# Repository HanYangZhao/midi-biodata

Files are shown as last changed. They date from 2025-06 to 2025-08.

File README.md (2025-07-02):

# MIDI Biodata Sonification Device

This repository was built upon code from https://github.com/electricityforprogress/BiodataFeather

Here you find the hardware and enclosure design files for the MIDI Biodata Sonification Devices

- enclosures: contains FreeCAD design and STL files for the enclosure
- firmware: 
  - MIDI_Psychogalv_328p_v021: unmodified firmware from electricityforprogress/MIDIsprout
  - arduino-nano: firmware for MIDI Biodata Sonification Device by me. This firmware offers the following new features over original version
    - Instead of menus, we use a web page to configure the device. The webpage uses webserial to send a json config to the board.
    - Allow all 7 modes of the major scale to be selected. I'm also included the chromatic and Raga Bhairav scale.
    - Selectable root note
    - Chord drone with selectable bpm and frequency. The chord is a triad based on the scale chosen.
    - Refactored code into multipe files for easier understanding.
    - Remove menu codes to save space, some optimization to free up the stack.
  - esp32: Same as main but for ESP32, the arduino-LEDFader folder needs to be copied to .../Arduino/Libraries. This firmware offer the additional:
    - 12 presets can be configured, each preset contains its own scale and root note, and can be triggered via MIDI CC/PC/NOTE
    - BLE MIDI support
- kicad: hardware design as KiCAD project and Gerber files. The board is designed to be used add-on to any microcontroller but also has footprint for the esp32s3 supermini board.

The hardware design and firmware is based on the work of electricityforprogress and thus licensed under the MIT license.

The enclosure design is however licensed under CC0 (public domain), except for the logo which is under copyright of [DipthDesign](https://www.dipth.de). For private use, anyone is free to print the enclosure with logo and without permission.

## Installation 

### Arduino nano

Download https://github.com/jgillick/arduino-LEDFader/tree/master to .../Arduino/Libraries

### ESP32

* Copy ./firmware/esp32/arduino-LEDFader to .../Arduino/Libraries
* Install arduino tiny usb library
* Device mode only support S2/S3/P4 and additional Tools menu are needed
    USB Mode=USB-OTG (TinyUSB) for S3 and P4
    USB CDC On Boot=Enabled, USB Firmware MSC On Boot=Disabled, USB DFU On Boot=Disabled
* BLE MIDI only works on ESP32-S3

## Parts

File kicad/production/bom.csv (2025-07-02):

Designator | Footprint | Quantity | Value | LCSC Part #
_4, _3, _2, | Fiducial_1mm_Dia_2.54mm_Outer_CopperTop | 4 | Fiducial_1mm_Dia_2.54mm_Outer_CopperTop
C1, C2, C4, C6 | 0402 | 4 | 0.1uF | C1525
C3 | 0402 | 1 | 4.7nF | C1538
C5 | CP_Radial_D5.0mm_P2.50mm | 1 | 100uF
D1 | D_SOD-123 | 1 | 1N4148W | C81598
D2 | 0603 | 1 | LED_WHITE | C2290
D3 | 0805 | 1 | LED_BLUE | C34499
D4 | 0805 | 1 | LED_GREEN | C2297
D5 | 0805 | 1 | LED_YELLOW | C2296
D6, D7 | 0603 | 2 | LED_RED | C2286
D8, D9 | D_SOD-882 | 2 | D_TVS | C294611
J1, J8 | DIN-5-MIDI-JACK | 2 | DIN-5_180degree
J3 | PinHeader_1x13_P2.54mm_Vertical | 1 | Conn_01x14_Pin
J7 | PinHeader_1x02_P2.54mm_Vertical | 1 | Conn_01x02_Socket
R1, R10, R11, R2, R3, R4, R5, R8, R9 | 0402 | 9 | 220R | C25091
R12 | 0805 | 1 | 470 | C17710
R6 | 0402 | 1 | 100K | C25741
R7 | 0805 | 1 | 3.9K | C17614
U1 | SOT-23-5 | 1 | SN74LVC1G07DBVR | C7829
U2 | tlp2362 | 1 | TLP2362TPR_E | C37658
U3 | DIP-8_W7.62mm | 1 | LMC555xM
U4 | MODULE_ESP32-C3_SUPERMINI_TH | 1 | ESP32-S3_SUPERMINI_TH

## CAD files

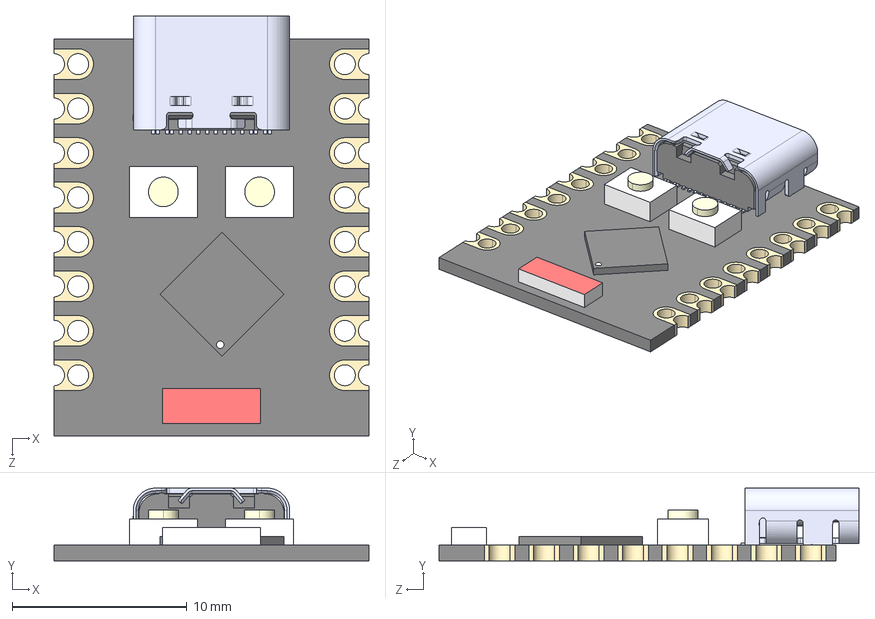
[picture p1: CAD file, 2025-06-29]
kicad/esp32s3/ESP32-C3_SUPERMINI_TH.step
18.0 x 4.16 x 24.0 mm
Board c3mini
USB C
components (other)^ESP32-C3 SuperMini

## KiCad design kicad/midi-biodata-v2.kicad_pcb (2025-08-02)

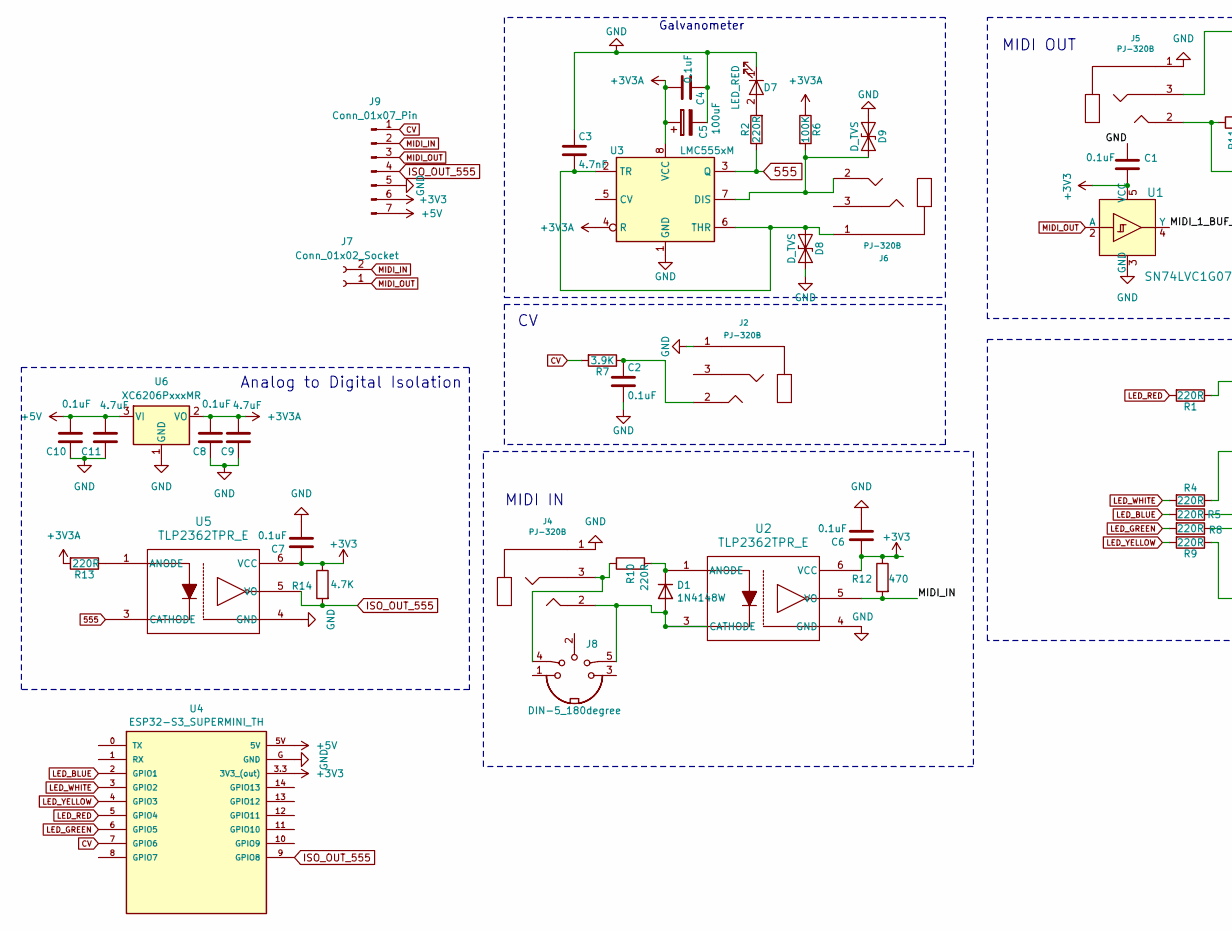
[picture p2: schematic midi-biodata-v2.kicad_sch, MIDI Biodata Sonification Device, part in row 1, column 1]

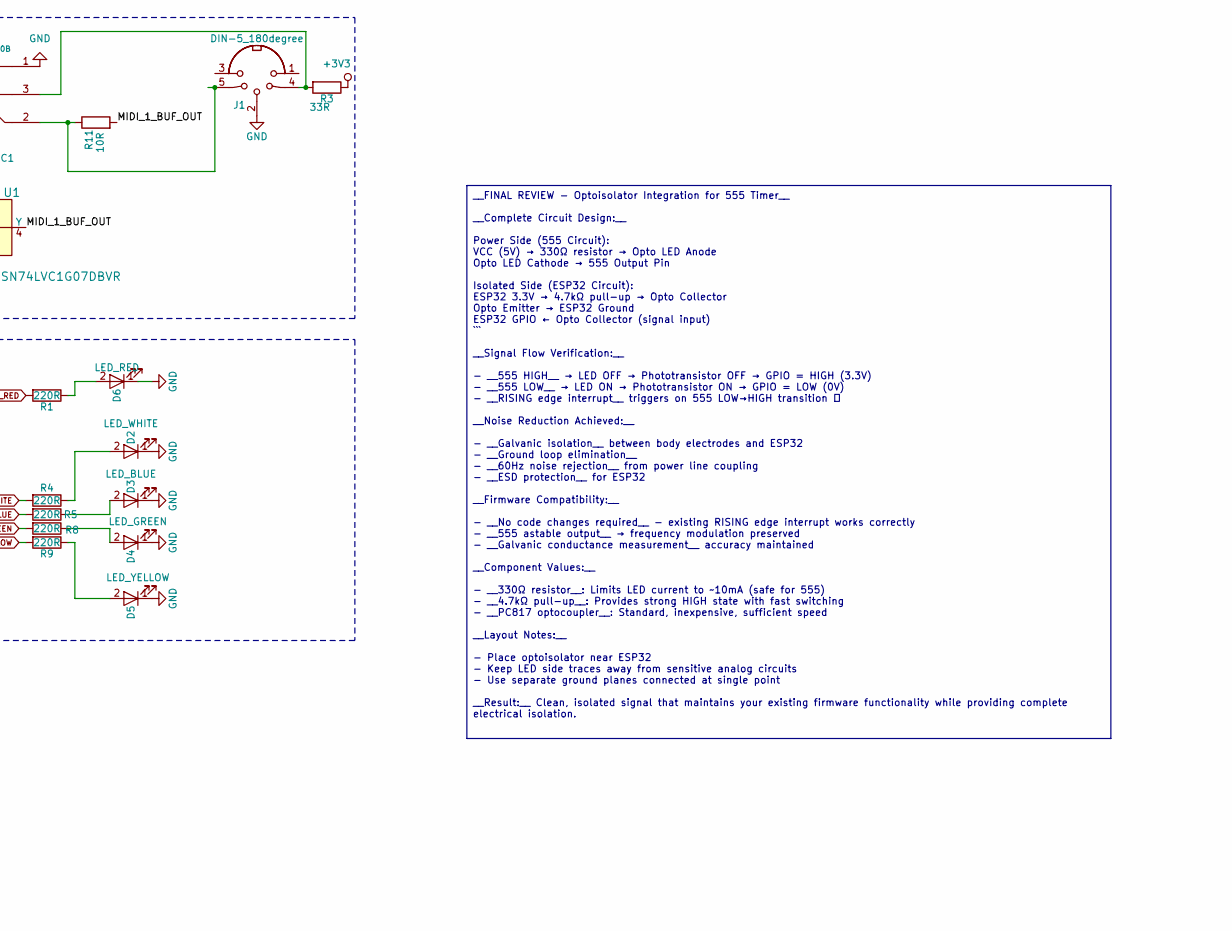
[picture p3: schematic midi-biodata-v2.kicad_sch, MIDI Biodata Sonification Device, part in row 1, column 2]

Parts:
C1, C2, C4, C6, C7, C8, C10: 0.1uF; C_0402_1005Metric; LCSC C1525
C3: 4.7nF; C_0402_1005Metric; LCSC C1538
C5: 100uF; CP_Radial_D5.0mm_P2.50mm
C9, C11: 4.7uF; C_0402_1005Metric; LCSC C23733
D1: 1N4148W; D_SOD-123; LCSC C81598
D2: LED_WHITE; D_0603_1608Metric_Pad1.05x0.95mm_HandSolder; LCSC C2290
D3: LED_BLUE; D_0805_2012Metric_Pad1.15x1.40mm_HandSolder; LCSC C34499
D4: LED_GREEN; D_0805_2012Metric_Pad1.15x1.40mm_HandSolder; LCSC C2297
D5: LED_YELLOW; D_0805_2012Metric_Pad1.15x1.40mm_HandSolder; LCSC C2296
D6, D7: LED_RED; D_0603_1608Metric_Pad1.05x0.95mm_HandSolder; LCSC C2286
D8, D9: D_TVS; D_SOD-882; LCSC C294611
J1, J8: DIN-5_180degree; DIN-5-MIDI-JACK
J2, J4, J5, J6: PJ-320B; 3.5mm_stereo_jack_PJ320B_THRU; LCSC C2884998
J7: Conn_01x02_Socket; PinHeader_1x02_P2.54mm_Vertical
J9: Conn_01x07_Pin; PinHeader_1x07_P2.54mm_Vertical
R1, R2, R4, R5, R8, R9, R10, R13: 220R; R_0402_1005Metric; LCSC C25091
R3: 33R; R_0402_1005Metric; LCSC C25105
R6: 100K; R_0402_1005Metric; LCSC C25741
R7: 3.9K; R_0805_2012Metric; LCSC C17614
R11: 10R; R_0402_1005Metric; LCSC C25077
R12: 470; R_0805_2012Metric; LCSC C17710
R14: 4.7K; R_0805_2012Metric; LCSC C17710
U1: SN74LVC1G07DBVR; SOT-23-5; Digi-Key_PN 296-8485-1-ND
U2, U5: TLP2362TPR_E; tlp2362; LCSC C37658
U3: LMC555xM; DIP-8_W7.62mm
U4: ESP32-S3_SUPERMINI_TH; MODULE_ESP32-C3_SUPERMINI_TH
U6: XC6206PxxxMR; SOT-23-3

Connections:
555: R2.1, U3.3 (Q), U5.3 (CATHODE)
+3V3: C1.2, C6.1, C7.1, J9.6, R3.1, R12.1, R14.1, U1.5 (VCC), U2.6 (VCC), U4.3.3 (3V3_(out)), U5.6 (VCC)
+3V3A: C4.2, C5.1, C8.2, C9.2, R6.1, R13.2, U3.4 (R), U3.8 (VCC), U6.2 (VO)
+5V: C10.2, C11.2, J9.7, U4.5V, U6.3 (VI)
/MIDI_1_BUF_OUT: R11.2, U1.4 (Y)
CV: J9.1, R7.2, U4.7 (GPIO6)
GND: C1.1, C2.2, C3.1, C4.1, C5.2, C6.2, C7.2, C8.1, C9.1, C10.1, C11.1, D2.1 (K), D3.1 (K), D4.1 (K), D5.1 (K), D6.1 (K), D7.1 (K), D8.2 (A2), D9.1 (A1), J1.2, J2.1, J4.1, J5.1, J9.5, U1.3 (GND), U2.4 (GND), U3.1 (GND), U4.G (GND), U5.4 (GND), U6.1 (GND)
ISO_OUT_555: J9.4, R14.2, U4.9 (GPIO8), U5.5 (VO)
LED_BLUE: R5.2, U4.2 (GPIO1)
LED_GREEN: R8.2, U4.6 (GPIO5)
LED_RED: R1.2, U4.5 (GPIO4)
LED_WHITE: R4.2, U4.3 (GPIO2)
LED_YELLOW: R9.2, U4.4 (GPIO3)
MIDI_IN: J7.2, J9.2, R12.2, U2.5 (VO)
MIDI_OUT: J7.1, J9.3, U1.2 (A)
unnamed: C2.1, J2.2, R7.1
unnamed: D1.2 (A), J4.2, J8.5, U2.3 (CATHODE)
unnamed: D1.1 (K), R10.2, U2.1 (ANODE)
unnamed: D2.2 (A), R4.1
unnamed: D3.2 (A), R5.1
unnamed: D4.2 (A), R8.1
unnamed: D5.2 (A), R9.1
unnamed: D6.2 (A), R1.1
unnamed: D7.2 (A), R2.2
unnamed: C3.2, D8.1 (A1), J6.1, U3.2 (TR), U3.6 (THR)
unnamed: D9.2 (A2), J6.2, R6.2, U3.7 (DIS)
unnamed: J1.4, J5.3, R3.2
unnamed: J1.5, J5.2, R11.1
unnamed: J4.3, J8.4, R10.1
unnamed: R13.1, U5.1 (ANODE)

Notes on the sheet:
__FINAL REVIEW - Optoisolator Integration for 555 Timer__ __Complete Circuit Design:__ Power Side (555 Circuit): VCC (5V) → 330Ω resistor → Opto LED Anode Opto LED Cathode → 555 Output Pin Isolated Side (ESP32 Circuit): ESP32 3.3V → 4.7kΩ pull-up → Opto Collector Opto Emitter → ESP32 Ground ESP32 G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
Galvanometer
MIDI IN
Analog to Digital Isolation
MIDI OUT

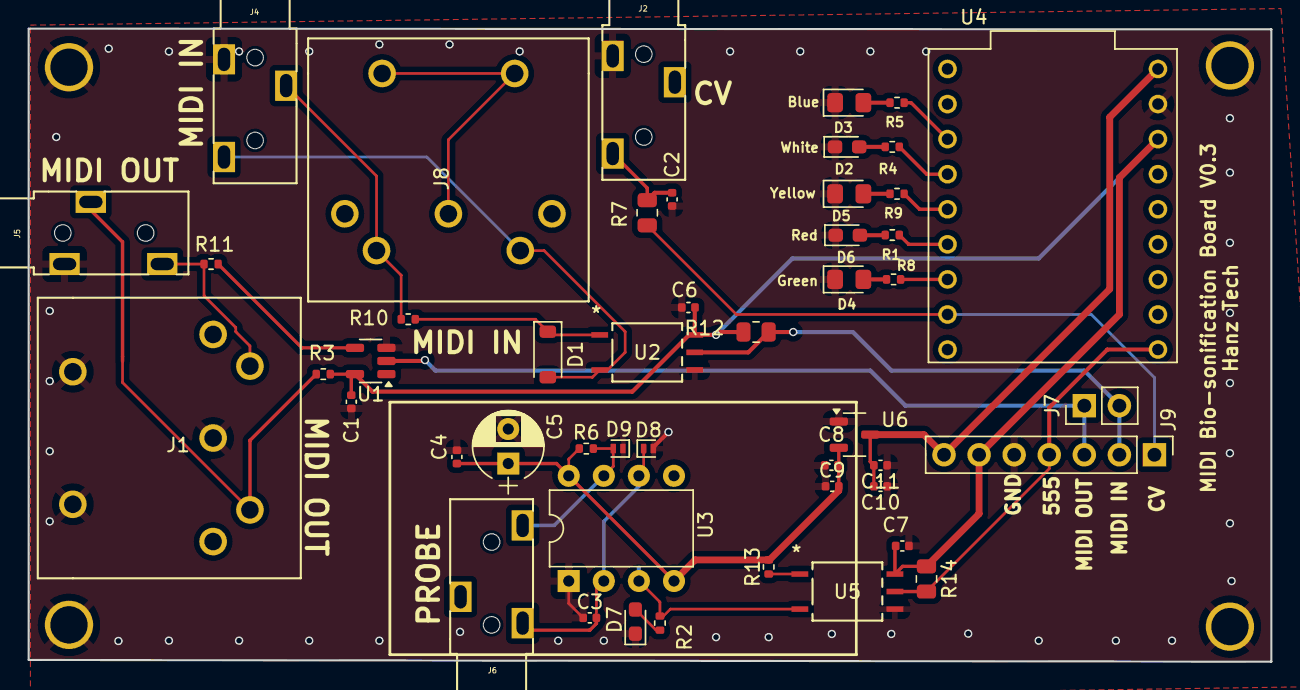
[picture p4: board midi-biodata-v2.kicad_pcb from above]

Board: 2 copper layers, 90.0 x 45.8 mm, 48 parts (0 on the bottom side), 30 nets.

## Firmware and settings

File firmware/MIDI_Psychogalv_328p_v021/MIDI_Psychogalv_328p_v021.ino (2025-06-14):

/*------------
MIDI_PsychoGalvanometer v021
Accepts pulse inputs from a Galvanic Conductance sensor 
consisting of a 555 timer set as an astablemultivibrator and two electrodes. 
Through sampling pulse widths and identifying fluctuations, MIDI note and control messages 
are generated.  Features include Threshold, Scaling, Control Number, and Control Voltage 
using PWM through an RC Low Pass filter.
MIDIsprout.com
-------------*/

#include <LEDFader.h> //manage LEDs without delay() jgillick/arduino-LEDFader https://github.com/jgillick/arduino-LEDFader.git

//******************************
//set scaled values, sorted array, first element scale length
int scaleMajor[]  = {7,1, 3, 5, 6, 8, 10, 12};
int scaleDiaMinor[]  = {7,1, 3, 4, 6, 8, 9, 11};
int scaleIndian[]  = {7,1, 2, 2, 5, 6, 9, 11};
int scaleMinor[]  = {7,1, 3, 4, 6, 8, 9, 11};
int scaleChrom[] = {12,1,2,3,4,5,6,7,8,9,10,11,12};
int *scaleSelect = scaleChrom; //initialize scaling
int root = 0; //initialize for root
//*******************************

const byte interruptPin = INT0; //galvanometer input
const byte knobPin = A0; //knob analog input

const byte samplesize = 10; //set sample array size
const byte analysize = samplesize - 1;  //trim for analysis array

const byte polyphony = 5; //above 8 notes may run out of ram
byte channel = 1;  //setting channel to 11 or 12 often helps simply computer midi routing setups
int noteMin = 36; //C2  - keyboard note minimum
int noteMax = 96; //C7  - keyboard note maximum
byte QY8= 0;  //sends each note out chan 1-4, for use with General MIDI like Yamaha QY8 sequencer
byte controlNumber = 80; //set to mappable control, low values may interfere with other soft synth controls!!
byte controlVoltage = 1; //output PWM CV on controlLED, pin 17, PB3, digital 11 *lowpass filter
long batteryLimit = 3000; //voltage check minimum, 3.0~2.7V under load; causes lightshow to turn off (save power)
byte checkBat = 1;

volatile unsigned long microseconds; //sampling timer
volatile byte index = 0;
volatile unsigned long samples[samplesize];

float threshold = 2.3;  //change threshold multiplier
float threshMin = 1.00; //scaling threshold min
float threshMax = 3.71; //scaling threshold max
float knobMin = 1;
float knobMax = 1023;

unsigned long previousMillis = 0;
unsigned long currentMillis = 1;
unsigned long batteryCheck = 0; //battery check delay timer
 
#define LED_NUM 6
LEDFader leds[LED_NUM] = { // 6 LEDs (perhaps 2 RGB LEDs)
  LEDFader(3),
  LEDFader(5),
  LEDFader(6),
  LEDFader(9),
  LEDFader(10),
  LEDFader(11)  //Control Voltage output or controlLED
};
int ledNums[LED_NUM] = {3,5,6,9,10,11};
byte controlLED = 5; //array index of control LED (CV out)
byte noteLEDs = 1;  //performs lightshow set at noteOn event

typedef struct _MIDImessage { //build structure for Note and Control MIDImessages
  unsigned int type;
  int value;
  int velocity;
  long duration;
  long period;
  int channel;
} 
MIDImessage;
MIDImessage noteArray[polyphony]; //manage MIDImessage data as an array with size polyphony
int noteIndex = 0;
MIDImessage controlMessage; //manage MIDImessage data for Control Message (CV out)


void setup()
{
  pinMode(knobPin, INPUT);
  randomSeed(analogRead(0)); //seed for QY8 
  Serial.begin(31250);  //initialize at MIDI rate
  controlMessage.value = 0;  //begin CV at 0
  //MIDIpanic(); //dont panic, unless you are sure it is nessisary
  checkBattery(); // shut off lightshow if power is too low
  if(noteLEDs) bootLightshow(); //a light show to display on system boot
  attachInterrupt(interruptPin, sample, RISING);  //begin sampling from interrupt
  
}

void loop()
{
  currentMillis = millis();   //manage time
  checkBattery(); //on low power, shutoff lightShow, continue MIDI operation
  checkKnob(); //check knob value
  if(index >= samplesize)  { analyzeSample(); }  //if samples array full, also checked in analyzeSample(), call sample analysis   
  checkNote();  //turn off expired notes 
  checkControl();  //update control value
  //checkButton();  //not implemented in this build
  checkLED();  //LED management without delay()
  previousMillis = currentMillis;   //manage time
}

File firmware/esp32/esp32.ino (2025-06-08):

#include <Arduino.h>
#include <ArduinoJson.h>
#include "globals.h"
#include "eeprom_settings.h"
#include "led_control.h"
#include "midi_handling.h"
#include "sensor_processing.h"
#include "web_serial_config.h"

// Interrupt timing sample array
void sample() {
  if (sampleIndex < samplesize) {
    samples[sampleIndex] = micros() - microseconds;
    microseconds = samples[sampleIndex] + microseconds;
    sampleIndex += 1;
  }
}

void setup() {
  pinMode(KNOB_PIN, INPUT_PULLUP);
  pinMode(LED_PIN_5, OUTPUT); // Example: update as needed for your hardware
  pinMode(LED_PIN_1, OUTPUT);
  pinMode(LED_PIN_2, OUTPUT);
  pinMode(LED_PIN_3, OUTPUT);
  pinMode(LED_PIN_4, OUTPUT);




  randomSeed(analogRead(0));

  Serial.begin(115200);
  Serial1.begin(31250, SERIAL_8N1, MIDI_SERIAL1_RX_PIN, MIDI_SERIAL1_TX_PIN);

  // Factory reset: uncomment the next line, upload, then comment again and re-upload
  // initializeEEPROM();

  readSettings();
  // USB MIDI initialization (from Adafruit_TinyUSB example)
  if (!TinyUSBDevice.isInitialized()) {
    TinyUSBDevice.begin(0);
  }
  usb_midi.setStringDescriptor("TinyUSB MIDI");
  // This will also call usb_midi's begin()
  usbMIDI.begin(MIDI_CHANNEL_OMNI);

  bleMidiInit();

  printGlobals();
  MIDI.begin();
  setupMidiPresetHandlers();
  controlMessage.value = 0;
  if (noteLEDs) bootLightshow();
  attachInterrupt(interruptPin, sample, RISING);
}

void loop() {
  currentMillis = millis();

  bleMidiLoop();

  if (sampleIndex >= samplesize) {
    analyzeSample();
  }

  checkNote();

  // Serial.println("[CHECKPOINT] checkControl about to run");
  checkControl();
  // Serial.println("[CHECKPOINT] checkControl finished");

  checkLED();

  midiChordTick();

  // Process incoming MIDI messages (required for callbacks)
  MIDI.read();
  usbMIDI.read();

  // --- Only process JSON commands via web_serial_config ---
  processWebSerialConfig();
}

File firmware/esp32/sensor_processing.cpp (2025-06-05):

#include "sensor_processing.h"
#include "led_control.h"
#include "utils.h"
#include "midi_handling.h"
#include "scale_functions.h"
#include <math.h>

// long readVcc() {
//   long result;
//   ADMUX = _BV(REFS0) | _BV(MUX3) | _BV(MUX2) | _BV(MUX1);
//   delay(2);
//   ADCSRA |= _BV(ADSC);
//   while (bit_is_set(ADCSRA, ADSC));
//   result = ADCL;
//   result |= ADCH << 8;
//   result = 1126400L / result;
//   return result;
// }

void analyzeSample() {
  unsigned long averg = 0;
  unsigned long maxim = 0;
  unsigned long minim = 100000;
  float stdevi = 0;
  unsigned long delta = 0;
  byte change = 0;

  if (sampleIndex == samplesize) {
    unsigned long sampanalysis[analysize];
    for (byte i = 0; i < analysize; i++) {
      sampanalysis[i] = samples[i + 1];
      if (sampanalysis[i] > maxim) {
        maxim = sampanalysis[i];
      }
      if (sampanalysis[i] < minim) {
        minim = sampanalysis[i];
      }
      averg += sampanalysis[i];
      stdevi += sampanalysis[i] * sampanalysis[i];
    }

    averg = averg / analysize;
    stdevi = sqrt(stdevi / analysize - averg * averg);
    if (stdevi < 1) {
      stdevi = 1.0;
    }

    delta = maxim - minim;

    if (delta > (stdevi * globalSettings.threshold)) {
      change = 1;
    }

    if (change) {
      int dur = 150 + (map(delta % 127, 1, 127, 100, 2500));
      int ramp = 3 + (dur % 100);
      int notechannel = random(1, 5);

      // Velocity based on delta, mapped to velocityMin/velocityMax
      uint8_t velocity = map(delta, 0, 1023, globalSettings.velocityMin, globalSettings.velocityMax);
      if (velocity < globalSettings.velocityMin) velocity = globalSettings.velocityMin;
      if (velocity > globalSettings.velocityMax) velocity = globalSettings.velocityMax;

      static uint8_t previousNotes[2] = {0xFF, 0xFF};
      uint8_t setnote = map(averg % 127, 1, 127, globalSettings.noteMin, globalSettings.noteMax);
      setnote = scaleNote_fast(setnote, presets[activePreset].rootNote, presets[activePreset].scale, previousNotes);
      previousNotes[1] = previousNotes[0];
      previousNotes[0] = setnote;

      bool noteSent = false;
      if (QY8) {
        setNote(setnote, velocity, dur, notechannel,true);
        noteSent = true;
      } else {
        setNote(setnote, velocity, dur, globalSettings.channel, true);
        noteSent = true;
      }

      if (noteSent && globalSettings.ccEnable) {
        int ccValue = map(delta, 0, 1023, 0, 127);
        setControl(controlNumber, ccValue, ccValue, dur);
      }
    }

    sampleIndex = 0;
  }
}

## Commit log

2025-05-13 Removed MCU from board, added proper midi out
    [midi-biodata-v2-2025-03-30-20-26-48.sch, midi-biodata-v2.kicad_pcb, midi-biodata-v2.kicad_sch]
2025-05-13 send to jlcpcb
    [bom.csv, designators.csv, midi-biodata-v2.kicad_pcb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]
2025-05-27 fixed midi routing on the pcb board
    [midi-biodata-v2.kicad_pcb, midi-biodata-v2.kicad_sch]
2025-05-28 Fixed note scaling, fixed web configurator
    [globals.cpp, globals.h, midi_handling.cpp]
2025-05-29 fixed duplicate root note, cleaned up code to save memory, added droning chord feature
    [globals.cpp, globals.h, midi_handling.cpp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]
2025-05-29 updated drone velocity, otimized code for ram space
2025-06-01 add support for esp32
2025-06-01 Add LEDFader for esp32
2025-06-03 Add support for usb midi on esp32s2
2025-06-04 Added BLE, fixed MIDI cc
    [esp32.ino, globals.cpp, globals.h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]
2025-06-05 add drone velocity
2025-06-09 add firmware version in web ui, fix midi handling on cc and program change
    [globals.cpp, globals.h, midi_handling.cpp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]
2025-06-28 cleanup, changed footprint for 3.5mm jack
    [midi-biodata-v2.kicad_pcb, midi-biodata-v2.kicad_sch]
2025-06-29 Add esp32s2 supermini board
    [ESP32-C3_SUPERMINI_TH.step, midi-biodata-v2.kicad_sch]
2025-06-30 updated board with esp32 s3 mini integration
    [midi-biodata-v2.kicad_pcb, midi-biodata-v2.kicad_sch]
2025-06-30 fixed esp32s3 board
    [midi-biodata-v2.kicad_pcb]
2025-07-02 Fix BLE midi support for esp32s3
    [globals.cpp, globals.h, midi_handling.cpp]
2025-07-02 send v0.2 to production
    [bom.csv, designators.csv, midi-biodata-v2.kicad_pcb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]
2025-08-01 Update MIDI out resistors for 3.3v
    [midi-biodata-v2.kicad_pcb, midi-biodata-v2.kicad_sch]
2025-08-01 add notes for optoisolator placement
    [midi-biodata-v2.kicad_sch]
2025-08-02 update board to 0.3, add analog partition to board
    [midi-biodata-v2.kicad_pcb, midi-biodata-v2.kicad_sch]
